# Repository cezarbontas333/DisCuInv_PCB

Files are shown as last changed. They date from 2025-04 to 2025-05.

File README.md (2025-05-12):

# DisCuInv_PCB
DisCuInv is an inverter project that aims to implement a simpler power conversion strategy. The aim is to be used in solar to grid conduction, but this is only a prototype used in an educational environment to test different plant control algorithms which may be less computational intensive and less complex to implement, like PIDs or RSTs. It contains a KiCAD project, namely schematic and PCB design, that can be used to create Gerber files, BOM and CPL that can be sent to a manufacturer to create the boards. Additionally, a [proof of concept](https://github.com/cezarbontas333/DisCuInv_PID) program is provided in a separate repository that uses a PID to control the power conversion.

## Highlights
- Features integrated [half-bridge and gate drivers](https://www.infineon.com/cms/en/product/power/motor-control-ics/brushed-dc-motor-control-ics/single-half-bridge-ics/ifx007t/) that can sustain up to 40V DC inputs, but the module designed should use 24V DC.
- Control is done using Infineon's [PSoC C3M5](https://www.infineon.com/cms/en/product/microcontroller/32-bit-psoc-arm-cortex-microcontroller/32-bit-psoc-control-arm-cortex-m33-mcu/psoc-control-c3m/), a modern microcontroller with plenty of features designed for power conversion applications. Pins that are not dedicated to the specific application have been broken out to standard 2.54mm headers for additional expansion modules in testing and prototyping of bonus features.
- Has an integrated power source for the whole logic section of the board. No other power supplies needed, just a IEC C8 socket to be directly plugged.
- Contains on-board LEDs and buttons for testing purposes.

## Disclaimers
This project does not assume any liability or warranty in any state of functioning, including specified or not specified otherwise. The license included covers only the KiCAD project files as described by the schematic and boards design. Other files included as additional resources and dependencies such as component footprints, schematic symbols, datasheets or similar material are subject to their respective owners' licenses and should be treated as such. If any issues appear in this regard, please contact via the platforms issues section or email to the maintainer.

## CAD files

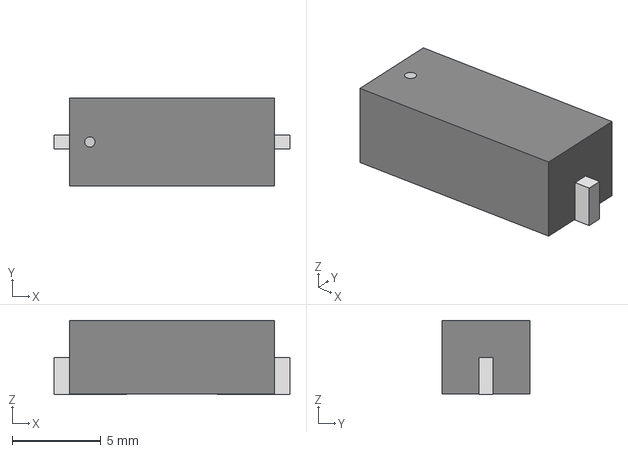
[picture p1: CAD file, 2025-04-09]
sol_inv/res/ABLS-16-000MHZ-B2-T/KiCADv6/XTAL_ABLS-16_ABR.step
13.3 x 4.98 x 4.19 mm

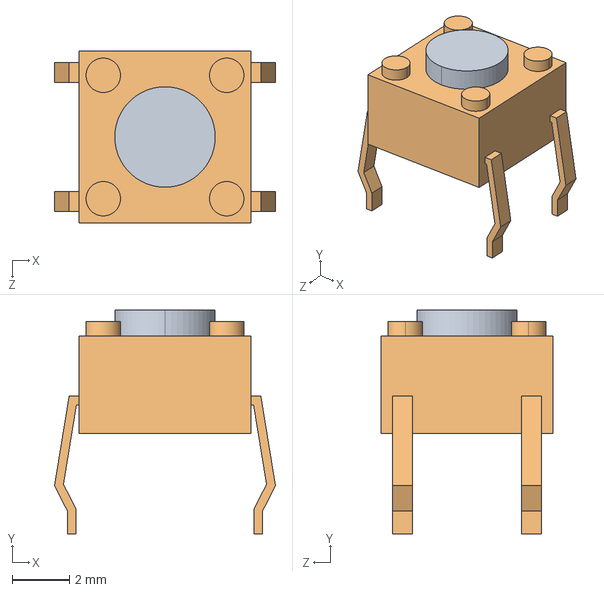
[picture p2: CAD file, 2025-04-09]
sol_inv/res/B3F-1000/KiCADv6/B3F_1000.step
7.70 x 7.80 x 6.00 mm
B3F_1002_BUTTON
B3F_1002_BASE

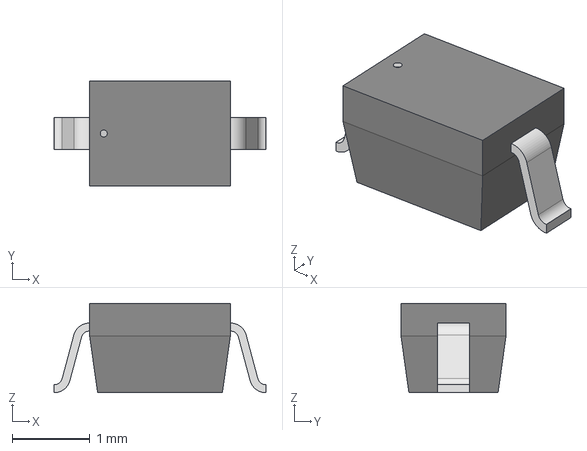
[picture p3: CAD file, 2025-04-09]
sol_inv/res/ESD12VD3B_TP/KiCADv6/CR_ESD_MCC.step
2.72 x 1.35 x 1.15 mm

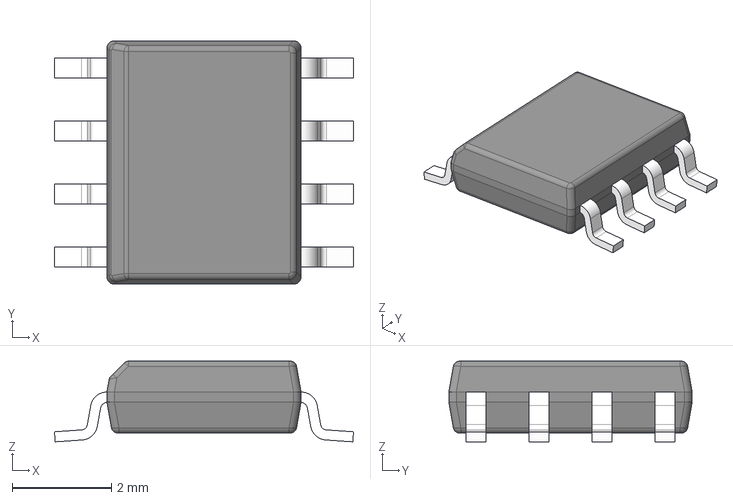
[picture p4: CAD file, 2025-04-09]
sol_inv/res/INA240A1D/KiCADv6/D0008A.stp
6.02 x 4.90 x 1.63 mm
BODY-SO
LEAD-D0008A x 8

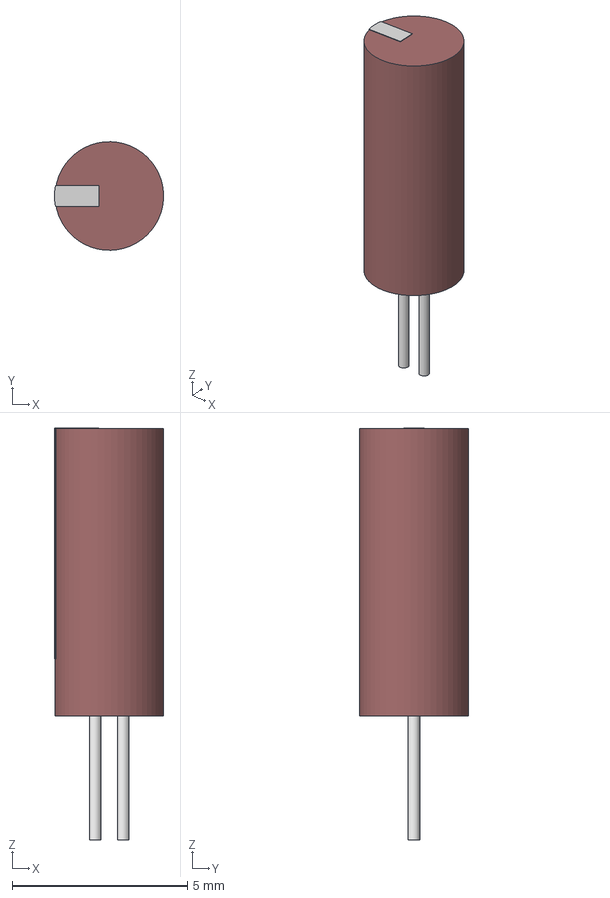
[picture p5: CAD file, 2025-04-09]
sol_inv/res/LFXTAL002995/KiCADv6/XTAL_LFXTAL002995BULK_IQD.step
3.11 x 3.10 x 11.8 mm

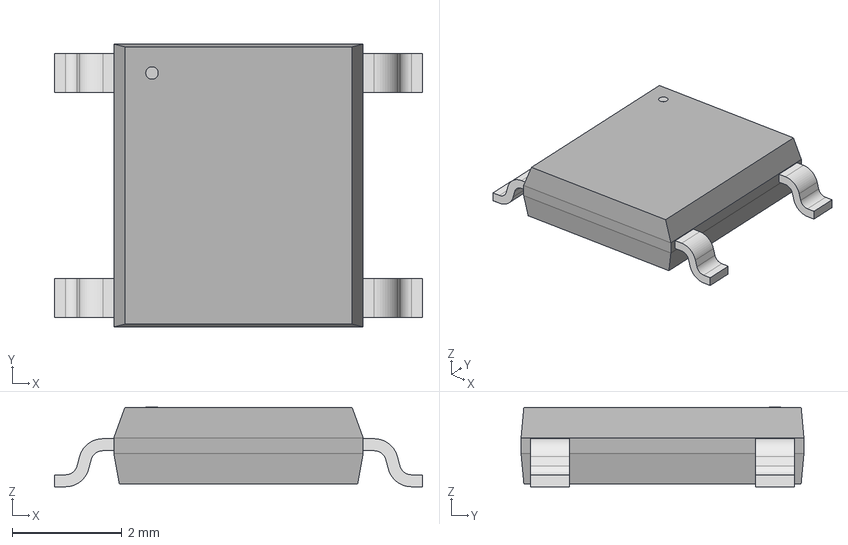
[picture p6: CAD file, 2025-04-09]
sol_inv/res/MDB6S/KiCADv6/BR_Micro-DIP4_OSI.step
6.71 x 5.16 x 1.45 mm

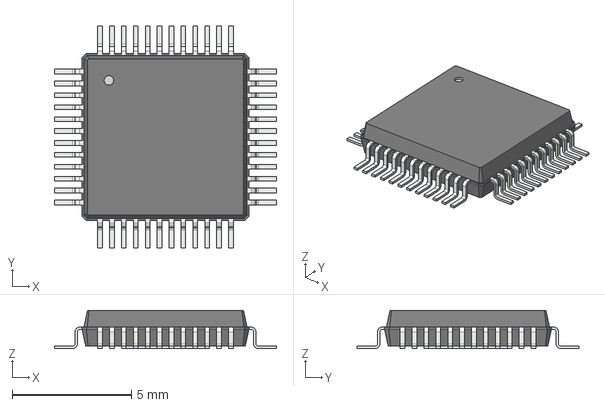
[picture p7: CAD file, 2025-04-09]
sol_inv/res/PSOC Control C3/Altium/E-LQFP-48/LQFP50P900X900X160-49N.step
9.32 x 9.32 x 1.60 mm

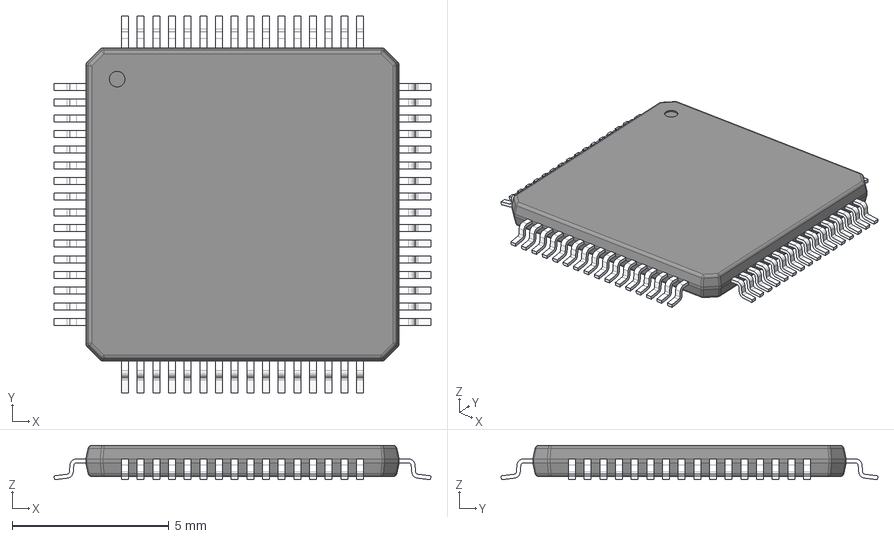
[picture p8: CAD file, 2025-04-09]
sol_inv/res/PSOC Control C3/Altium/E-LQFP-64/LQFP50P1200X1200X160-65N.stp
12.0 x 12.0 x 1.10 mm
BODY-QFP
LEAD-POWERPAD x 64
THERMALPAD-PWRPAD

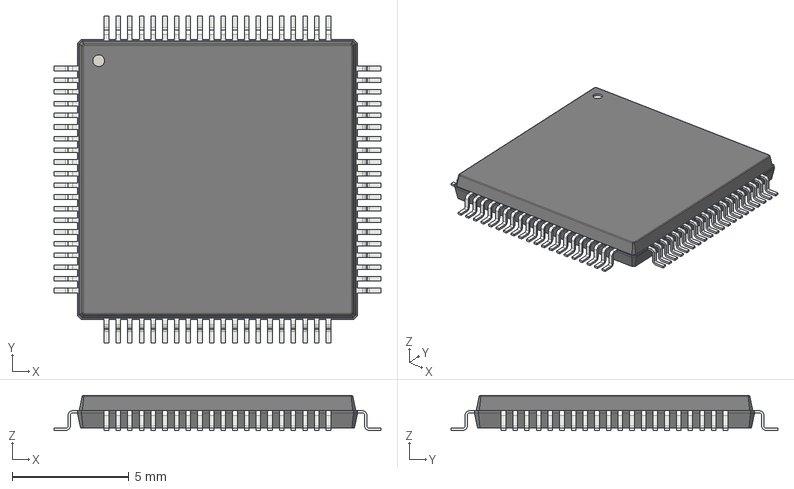
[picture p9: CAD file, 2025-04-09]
sol_inv/res/PSOC Control C3/Altium/E-LQFP-80/LQFP50P1400X1400X160-81N.step
14.0 x 14.0 x 1.50 mm

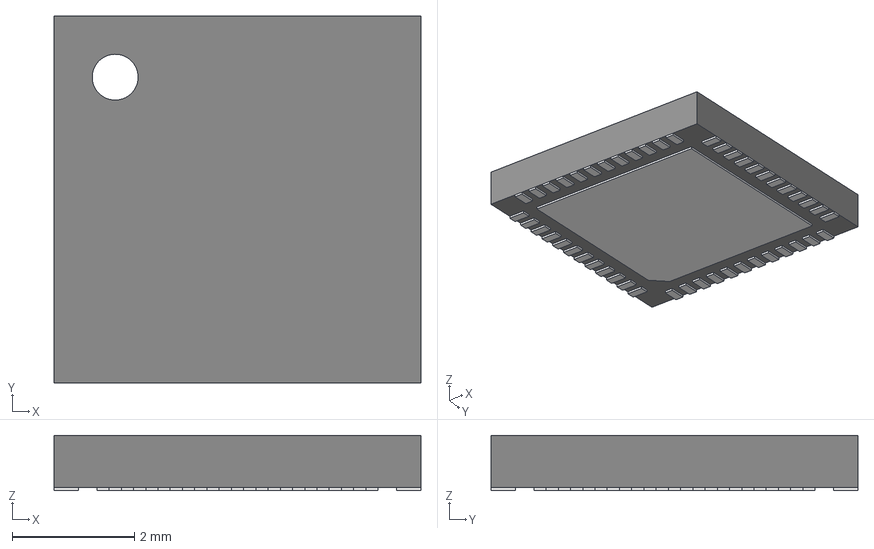
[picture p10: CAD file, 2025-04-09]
sol_inv/res/PSOC Control C3/Altium/VQFN-48/VQFN40P600X600X90-49N.step
6.00 x 6.00 x 0.9 mm
Open_CASCADE_STEP_translator_6.8_20.1
Open_CASCADE_STEP_translator_6.8_20.2.1
Thermal_Shape
Pin_Shape x 48

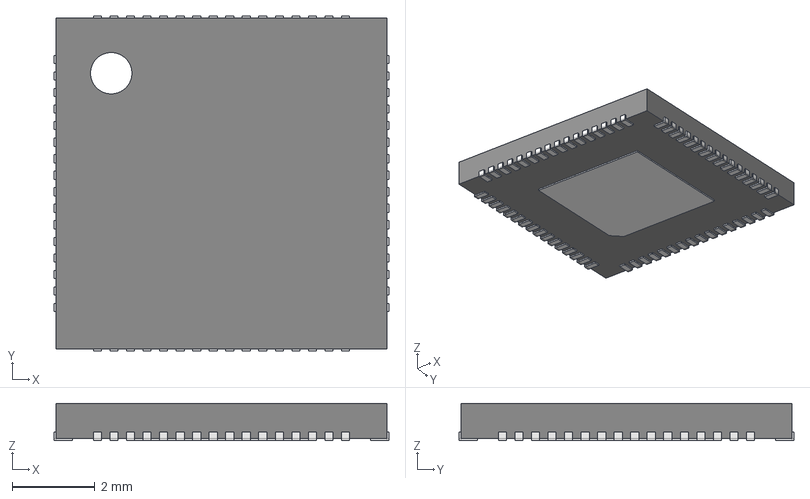
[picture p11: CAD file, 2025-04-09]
sol_inv/res/PSOC Control C3/Altium/VQFN-64/VQFN40P800X800X90-65N.step
8.10 x 8.10 x 0.9 mm
Open_CASCADE_STEP_translator_6.8_25.1
Open_CASCADE_STEP_translator_6.8_25.2.1
Thermal_Shape
Open_CASCADE_STEP_translator_6.8_25.4.1 x 64

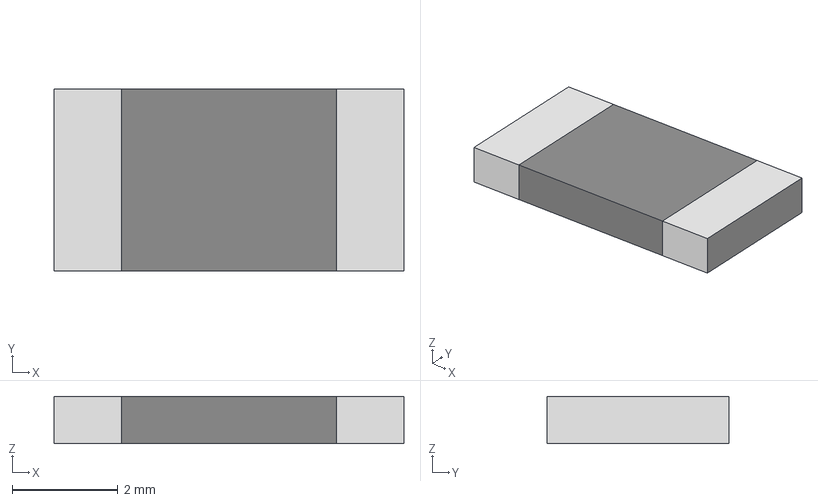
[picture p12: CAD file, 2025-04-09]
sol_inv/res/WSLP2512R0100FEA/KiCADv6/RES_VISHAY_WSLP2512_C_VIS.step
6.60 x 3.43 x 0.889 mm

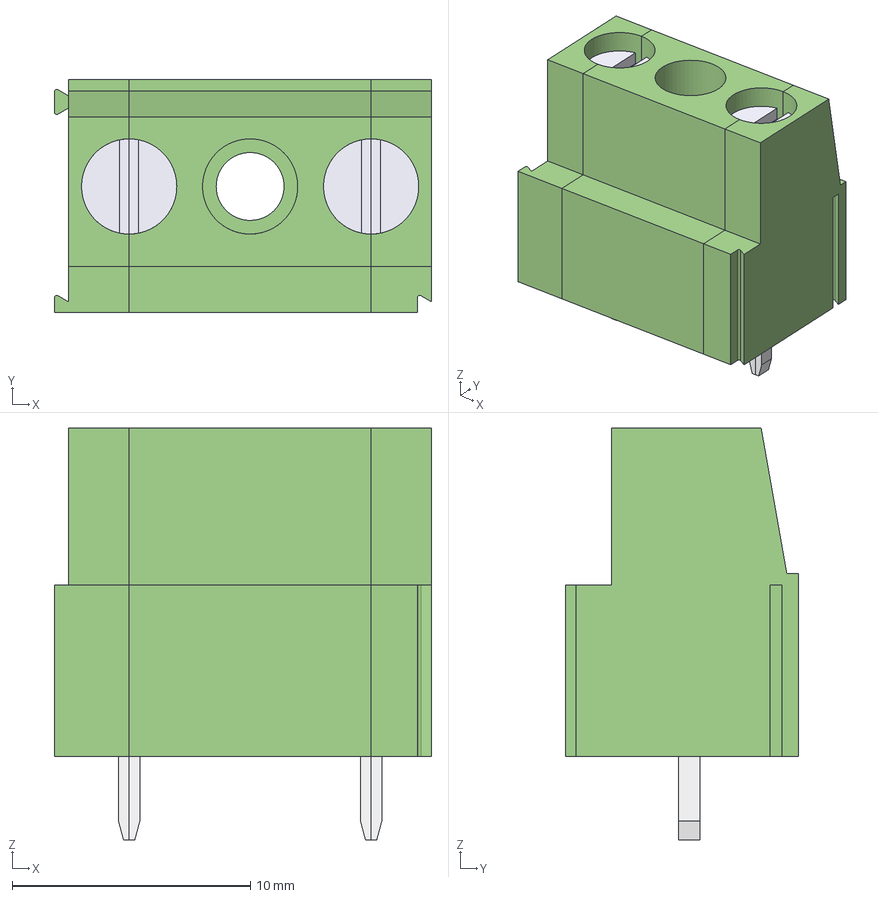
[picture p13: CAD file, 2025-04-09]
sol_inv/res/Wurth-691216610002/Download_STP_691216610002_rev1.stp
15.8 x 9.80 x 17.3 mm
CLL10.16_SX
CLL10.16_CNT
CLL10.16_DX

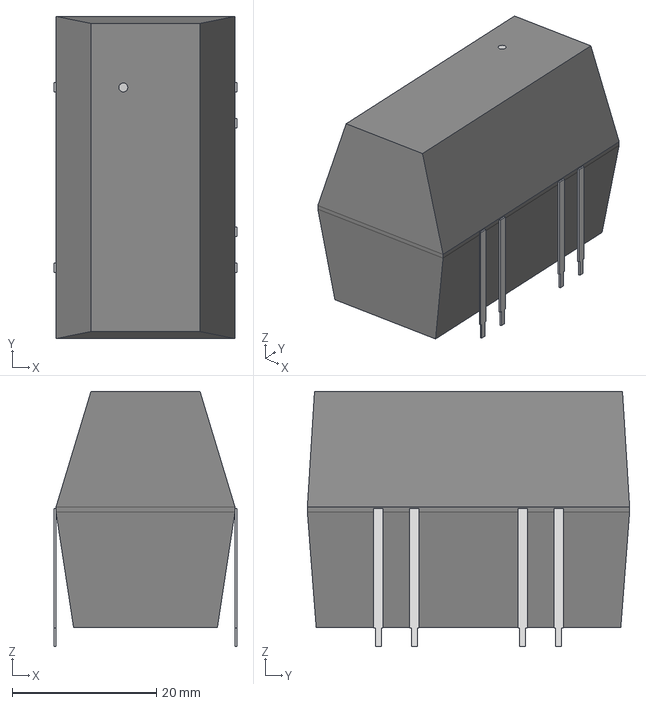
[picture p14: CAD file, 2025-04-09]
sol_inv/res/Myrra_44229/KiCADv6/44230_MYR.step
25.4 x 44.8 x 35.4 mm

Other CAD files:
sol_inv/res/WE-FLEX-749196521/749196521 (rev1).stp
sol_inv/res/WE-FLEX-749196521/749196521 (rev1).igs

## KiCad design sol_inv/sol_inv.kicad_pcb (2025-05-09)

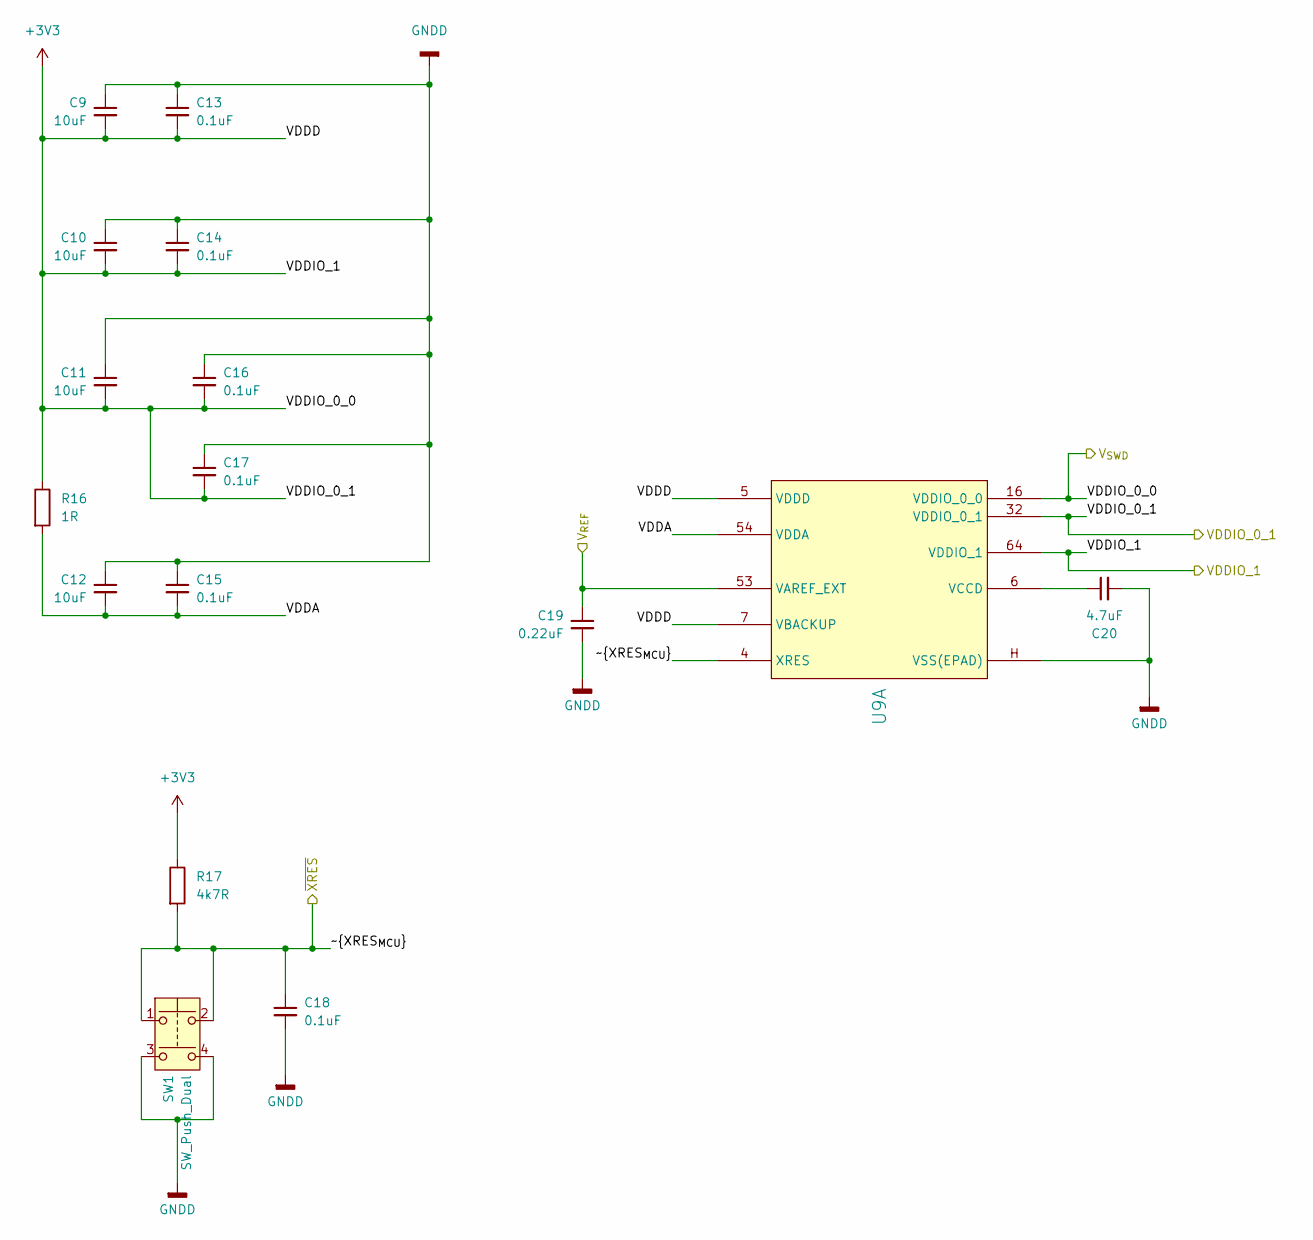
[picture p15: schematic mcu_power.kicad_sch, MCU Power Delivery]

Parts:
C9, C10, C11, C12: 10uF; C_0603_1608Metric
C13, C14, C15, C16, C17, C18: 0.1uF; C_0402_1005Metric
C19: 0.22uF; C_0402_1005Metric
C20: 4.7uF; C_0402_1005Metric
R16: 1R; R_0603_1608Metric
R17: 4k7R; R_0402_1005Metric
SW1: SW_Push_Dual; SW_B3F-1000_OMR
U9: PSC3M5_E-LQFP-64; LQFP50P1200X1200X160-65N

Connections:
+3V3: C9.2, C10.2, C11.2, C13.2, C14.2, C16.2, C17.2, R16.1, R17.1, U9.5 (VDDD), U9.7 (VBACKUP), U9.16 (VDDIO_0_0), U9.32 (VDDIO_0_1), U9.64 (VDDIO_1); also elsewhere on the board
/H-Bridge/V_{REF}: C19.1, U9.53 (VAREF_EXT); also elsewhere on the board
/MCU Power/VDDA: C12.2, C15.2, R16.2, U9.54 (VDDA)
/MCU Power/~XRES_{MCU}: C18.1, R17.2, SW1.1, SW1.2, U9.4 (XRES); also elsewhere on the board
GNDD: C9.1, C10.1, C11.1, C12.1, C13.1, C14.1, C15.1, C16.1, C17.1, C18.2, C19.2, C20.2, SW1.3, SW1.4, U9.H (VSS(EPAD)); also elsewhere on the board
unnamed: C20.1, U9.6 (VCCD)

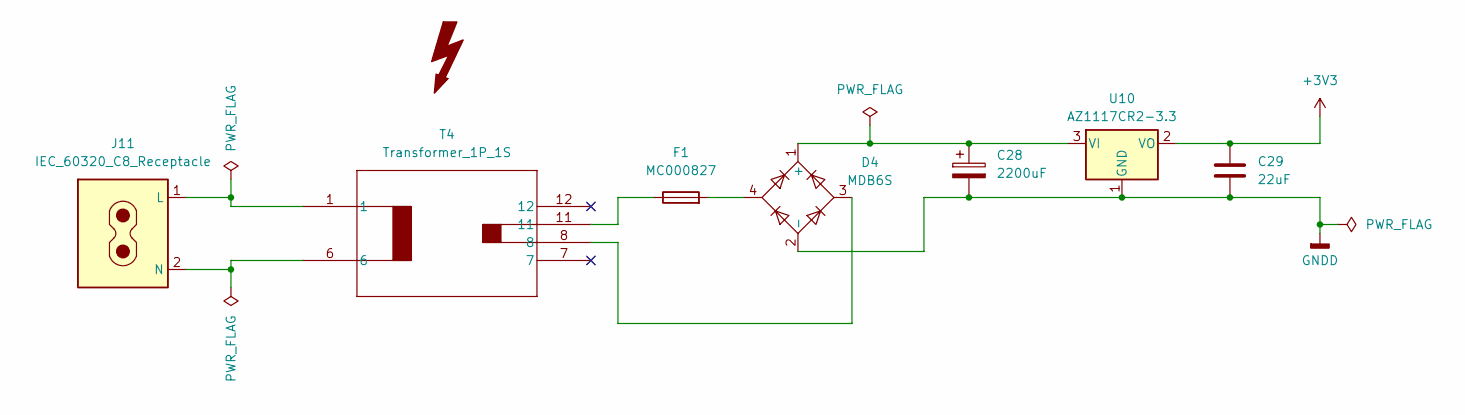
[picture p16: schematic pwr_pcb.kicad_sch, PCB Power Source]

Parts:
C28: 2200uF; CP_Radial_D10.0mm_P5.00mm
C29: 22uF; C_1206_3216Metric
D4: MDB6S; BR_Micro-DIP4_OSI
F1: MC000827; FUSE_MC000827_MTC
J11: IEC_60320_C8_Receptacle; 43000103
T4: Transformer_1P_1S; 44230_MYR
U10: AZ1117CR2-3.3; SOT-89-3

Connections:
+3V3: C29.1, U10.2 (VO); also elsewhere on the board
GNDD: C28.2, C29.2, D4.2 (-), U10.1 (GND); also elsewhere on the board
unnamed: C28.1, D4.1 (+), U10.3 (VI)
unnamed: D4.3, T4.8
unnamed: D4.4, F1.2
unnamed: F1.1, T4.11
unnamed: J11.1 (L), T4.1
unnamed: J11.2 (N), T4.6

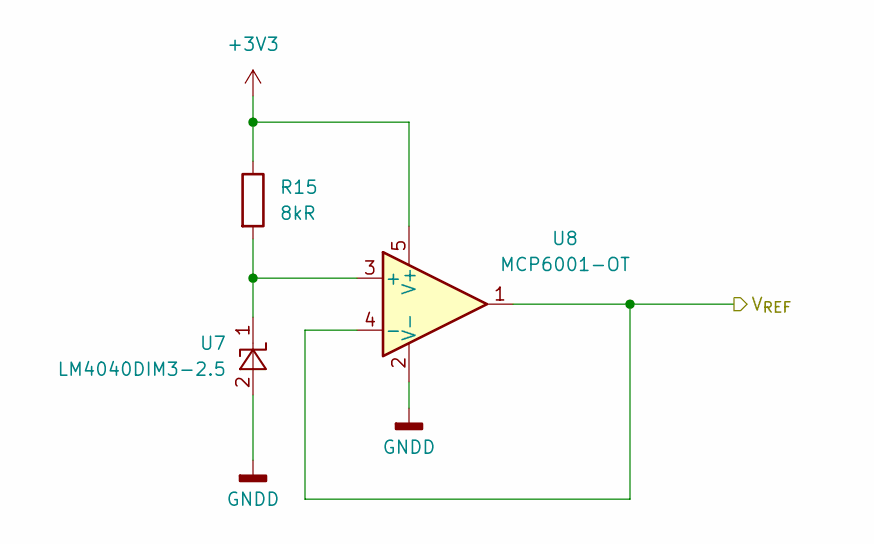
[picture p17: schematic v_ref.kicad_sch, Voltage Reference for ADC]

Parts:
R15: 8kR; R_0603_1608Metric
U7: LM4040DIM3-2.5; SOT-23-3
U8: MCP6001-OT; SOT-23-5

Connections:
+3V3: R15.1, U8.5 (V+); also elsewhere on the board
/H-Bridge/V_{REF}: U8.1, U8.4 (-); also elsewhere on the board
GNDD: U7.2 (A), U8.2 (V-); also elsewhere on the board
unnamed: R15.2, U7.1 (K), U8.3 (+)

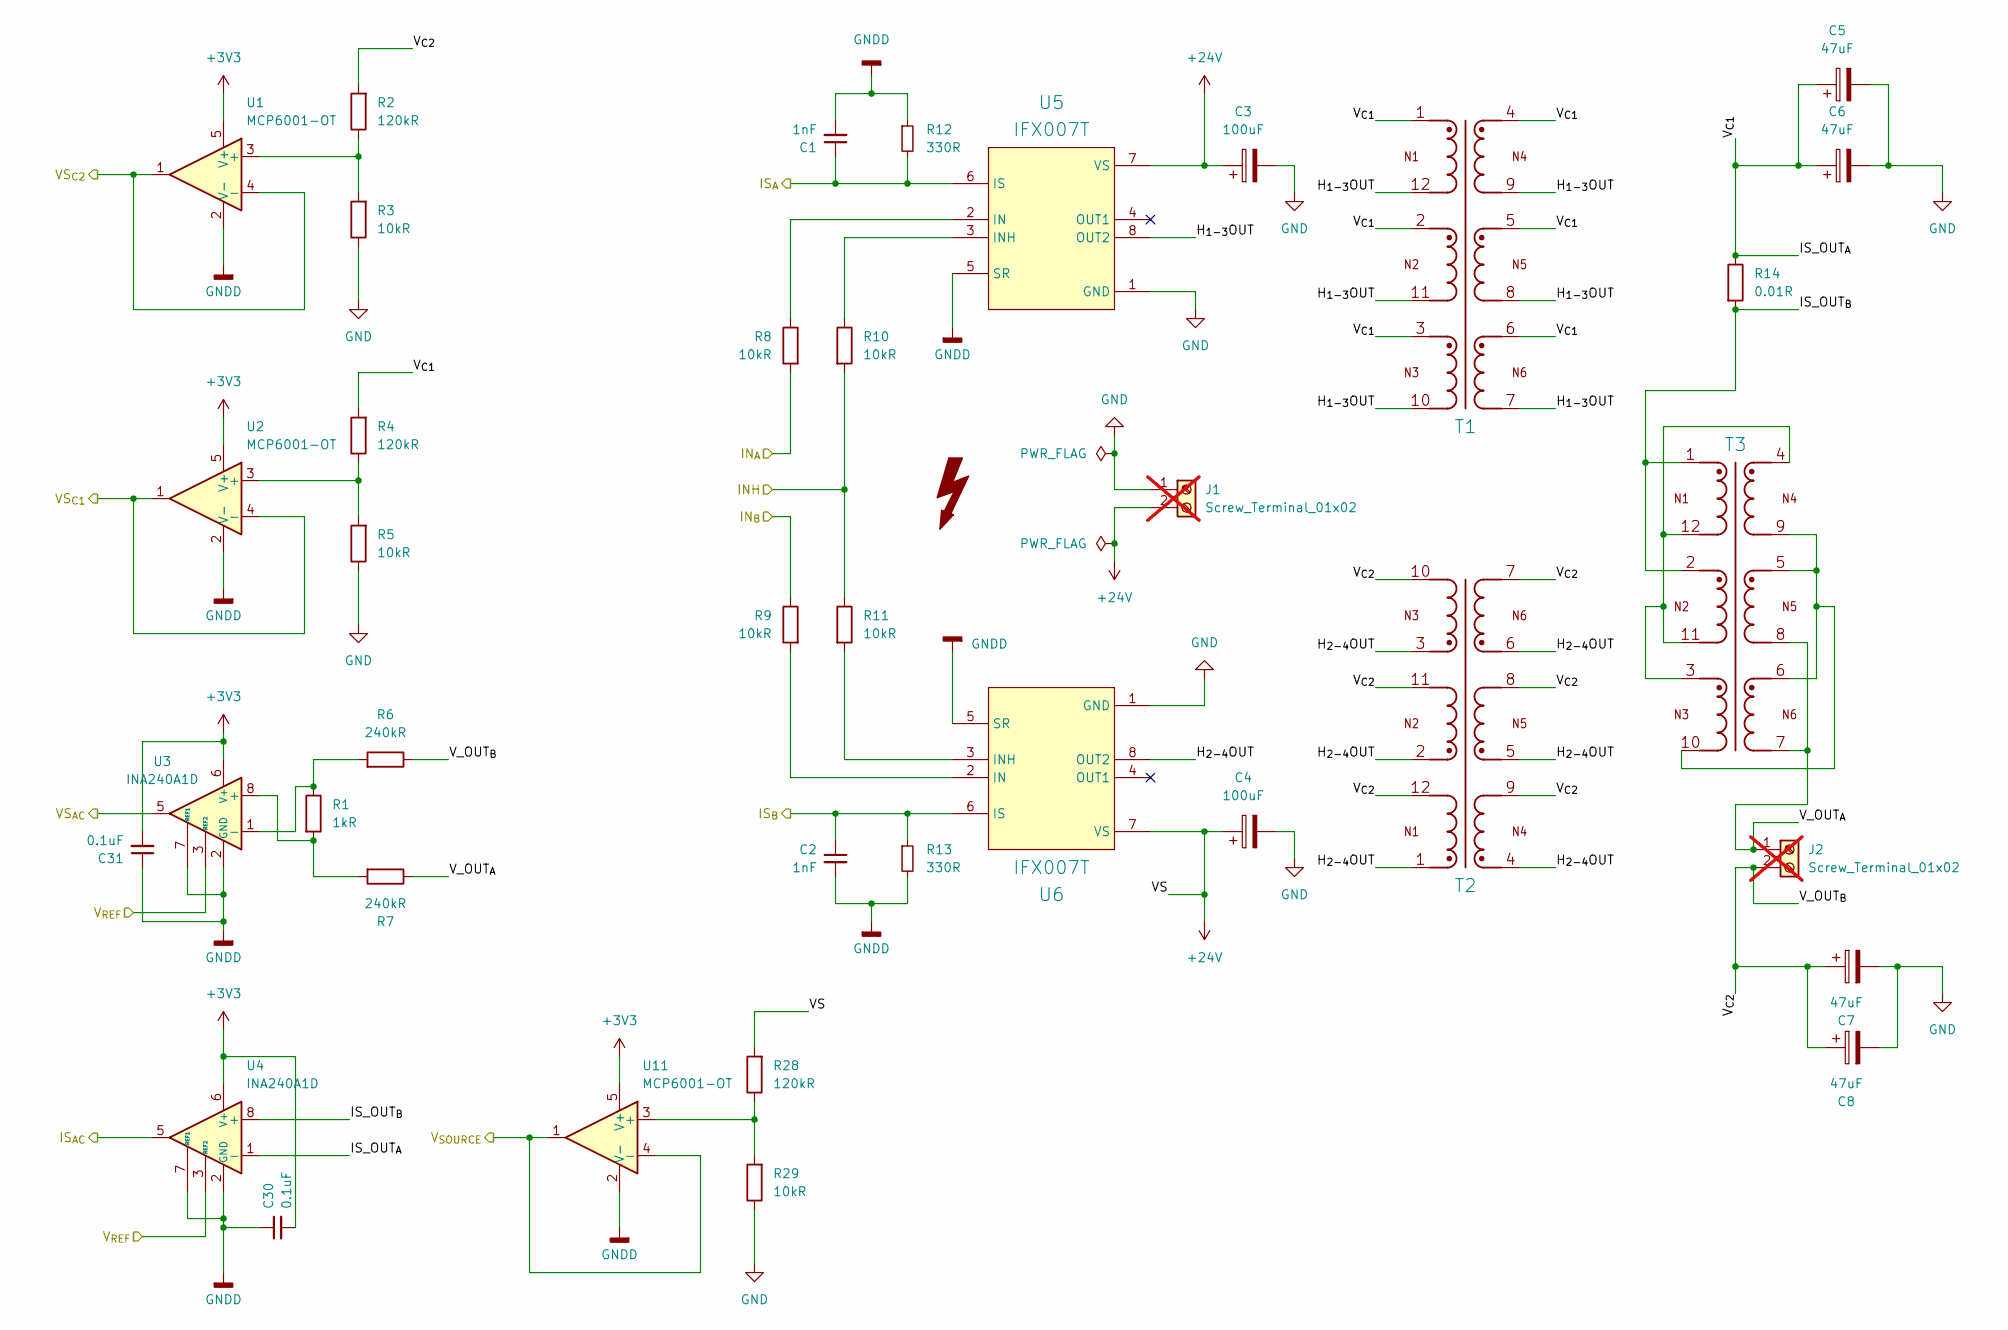
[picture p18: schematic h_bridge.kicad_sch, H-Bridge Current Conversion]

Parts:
C1, C2: 1nF; C_0603_1608Metric
C3, C4: 100uF; CP_Elec_8x10
C5, C6, C7, C8: 47uF; CP_Elec_8x10
C30, C31: 0.1uF; C_0402_1005Metric
J1, J2: Screw_Terminal_01x02; 691216610002_Handsolder; not fitted
R1: 1kR; R_0805_2012Metric
R2, R4, R28: 120kR; R_0805_2012Metric
R3, R5, R8, R9, R10, R11, R29: 10kR; R_0402_1005Metric
R6, R7: 240kR; R_0603_1608Metric
R12, R13: 330R; R_0603_1608Metric
R14: 0.01R; R_2512_6332Metric
T1, T2, T3: 12uH, 1.7A; WE-FLEX_EFD20; Voltage-µSecond Base 98.4uVs; Manufacturer Part Number 749196521
U1, U2, U11: MCP6001-OT; SOT-23-5
U3, U4: INA240A1D; D8_TEX
U5, U6: IFX007T; TO127P1500X440-8N-1-V

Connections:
+3V3: C30.2, C31.2, U1.5 (V+), U2.5 (V+), U3.6 (V+), U4.6 (V+), U11.5 (V+); also elsewhere on the board
+24V: C3.1, C4.1, J1.2, R28.2, U5.7 (VS), U6.7 (VS)
/H-Bridge/H_{1-3}OUT: T1.7, T1.8, T1.9, T1.10, T1.11, T1.12, U5.8 (OUT2)
/H-Bridge/H_{2-4}OUT: T2.1, T2.2, T2.3, T2.4, T2.5, T2.6, U6.8 (OUT2)
/H-Bridge/INH: R10.2, R11.1; also elsewhere on the board
/H-Bridge/IN_{A}: R8.2; also elsewhere on the board
/H-Bridge/IN_{B}: R9.1; also elsewhere on the board
/H-Bridge/IS_OUT_{A}: C5.1, C6.1, R4.2, R14.1, T1.1, T1.2, T1.3, T1.4, T1.5, T1.6, U4.1 (-)
/H-Bridge/IS_OUT_{B}: R14.2, T3.1, T3.2, U4.8 (+)
/H-Bridge/IS_{AC}: U4.5; also elsewhere on the board
/H-Bridge/IS_{A}: C1.1, R12.2, U5.6 (IS); also elsewhere on the board
/H-Bridge/IS_{B}: C2.1, R13.1, U6.6 (IS); also elsewhere on the board
/H-Bridge/VS_{AC}: U3.5; also elsewhere on the board
/H-Bridge/VS_{C1}: U2.1, U2.4 (-); also elsewhere on the board
/H-Bridge/VS_{C2}: U1.1, U1.4 (-); also elsewhere on the board
/H-Bridge/V_OUT_{A}: J2.1, R7.1, T3.7, T3.8
/H-Bridge/V_OUT_{B}: C7.1, C8.1, J2.2, R2.2, R6.1, T2.7, T2.8, T2.9, T2.10, T2.11, T2.12
/H-Bridge/V_{REF}: U3.3 (REF2), U4.3 (REF2); also elsewhere on the board
/H-Bridge/V_{SOURCE}: U11.1, U11.4 (-); also elsewhere on the board
GND: C3.2, C4.2, C5.2, C6.2, C7.2, C8.2, J1.1, R3.1, R5.1, R29.1, U5.1 (GND), U6.1 (GND)
GNDD: C1.2, C2.2, C30.1, C31.1, R12.1, R13.2, U1.2 (V-), U2.2 (V-), U3.2 (GND), U3.4 (GND), U3.7 (REF1), U4.2 (GND), U4.4 (GND), U4.7 (REF1), U5.5 (SR), U6.5 (SR), U11.2 (V-); also elsewhere on the board
unnamed: T3.5, T3.6, T3.9, T3.10
unnamed: T3.3, T3.4, T3.11, T3.12
unnamed: R2.1, R3.2, U1.3 (+)
unnamed: R4.1, R5.2, U2.3 (+)
unnamed: R1.2, R7.2, U3.8 (+)
unnamed: R1.1, R6.2, U3.1 (-)
unnamed: R8.1, U5.2 (IN)
unnamed: R10.1, U5.3 (INH)
unnamed: R9.2, U6.2 (IN)
unnamed: R11.2, U6.3 (INH)
unnamed: R28.1, R29.2, U11.3 (+)

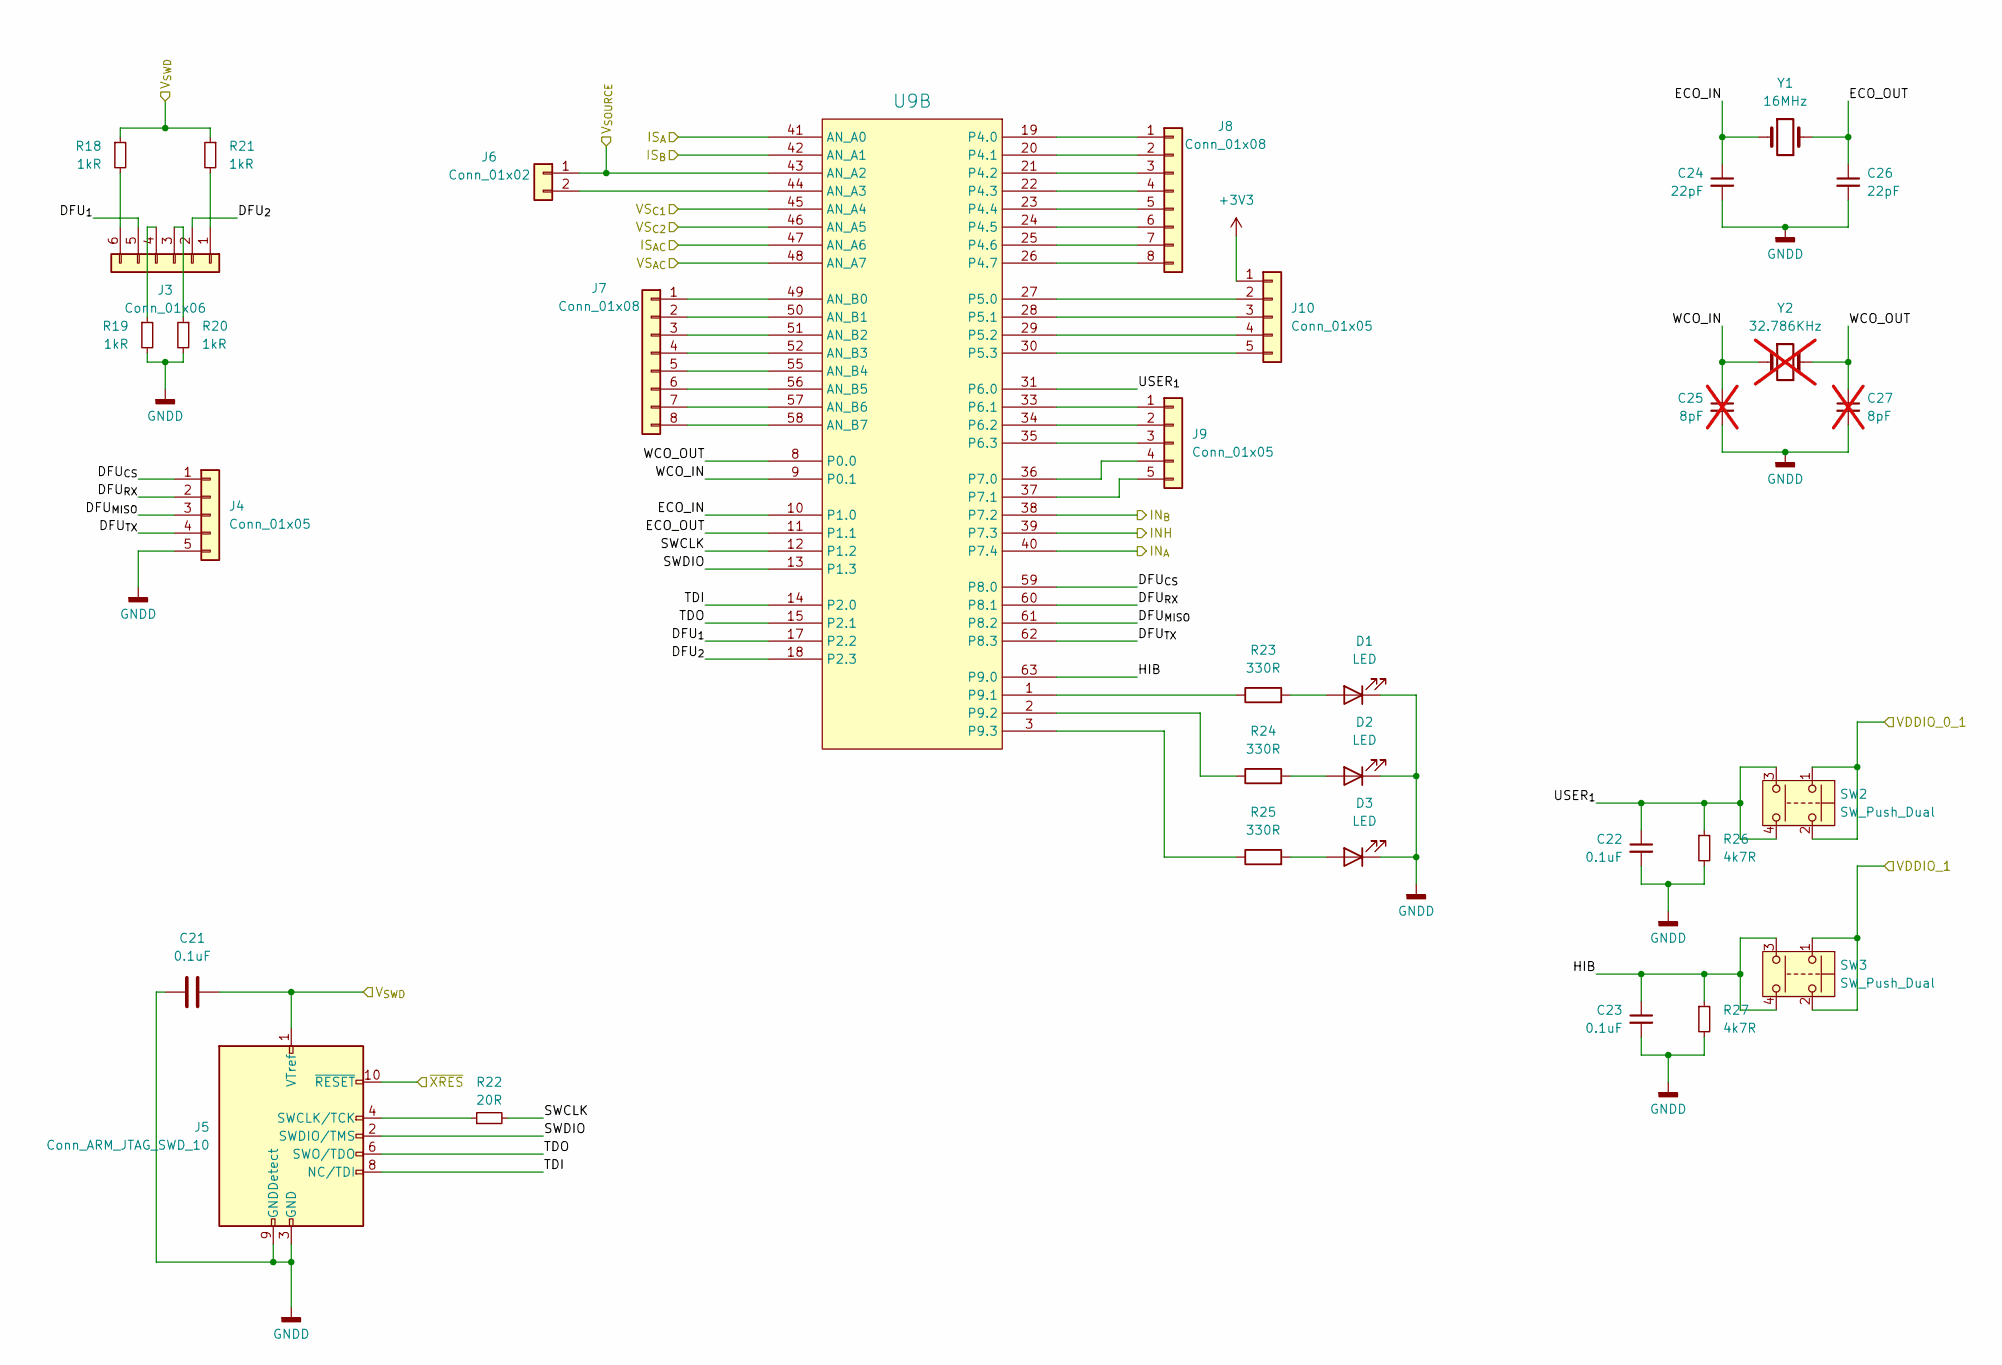
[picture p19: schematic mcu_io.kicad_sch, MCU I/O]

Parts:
C21, C22, C23: 0.1uF; C_0402_1005Metric
C24, C26: 22pF; C_0805_2012Metric
C25, C27: 8pF; C_0402_1005Metric; not fitted
D1, D2, D3: LED; LED_0603_1608Metric
J3: Conn_01x06; PinHeader_1x06_P2.54mm_Vertical
J4, J9, J10: Conn_01x05; PinSocket_1x05_P2.54mm_Vertical
J5: Conn_ARM_JTAG_SWD_10; PinHeader_2x05_P1.27mm_Vertical
J6: Conn_01x02; PinSocket_1x02_P2.54mm_Vertical
J7, J8: Conn_01x08; PinSocket_1x08_P2.54mm_Vertical
R18, R19, R20, R21: 1kR; R_0805_2012Metric
R22: 20R; R_1206_3216Metric
R23, R24, R25: 330R; R_0603_1608Metric
R26, R27: 4k7R; R_0402_1005Metric
SW2, SW3: SW_Push_Dual; SW_B3F-1000_OMR
U9: PSC3M5_E-LQFP-64; LQFP50P1200X1200X160-65N
Y1: 16MHz; ABLS7
Y2: 32.786KHz; XTAL_LFXTAL002995BULK_IQD; not fitted

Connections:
+3V3: C21.1, J5.1 (VTref), J10.1, R18.1, R21.1, SW2.1, SW2.2, SW3.1, SW3.2; also elsewhere on the board
/H-Bridge/INH: U9.39 (P7.3); also elsewhere on the board
/H-Bridge/IN_{A}: U9.40 (P7.4); also elsewhere on the board
/H-Bridge/IN_{B}: U9.38 (P7.2); also elsewhere on the board
/H-Bridge/IS_{AC}: U9.47 (AN_A6); also elsewhere on the board
/H-Bridge/IS_{A}: U9.41 (AN_A0); also elsewhere on the board
/H-Bridge/IS_{B}: U9.42 (AN_A1); also elsewhere on the board
/H-Bridge/VS_{AC}: U9.48 (AN_A7); also elsewhere on the board
/H-Bridge/VS_{C1}: U9.45 (AN_A4); also elsewhere on the board
/H-Bridge/VS_{C2}: U9.46 (AN_A5); also elsewhere on the board
/H-Bridge/V_{SOURCE}: J6.1, U9.43 (AN_A2); also elsewhere on the board
/MCU IO/DFU_{1}: J3.5, U9.17 (P2.2)
/MCU IO/DFU_{2}: J3.2, U9.18 (P2.3)
/MCU IO/DFU_{CS}: J4.1, U9.59 (P8.0)
/MCU IO/DFU_{MISO}: J4.3, U9.61 (P8.2)
/MCU IO/DFU_{RX}: J4.2, U9.60 (P8.1)
/MCU IO/DFU_{TX}: J4.4, U9.62 (P8.3)
/MCU IO/ECO_IN: C24.1, U9.10 (P1.0), Y1.1
/MCU IO/ECO_OUT: C26.1, U9.11 (P1.1), Y1.2
/MCU IO/HIB: C23.1, R27.1, SW3.3, SW3.4, U9.63 (P9.0)
/MCU IO/SWCLK: R22.2, U9.12 (P1.2)
/MCU IO/SWDIO: J5.2 (SWDIO/TMS), U9.13 (P1.3)
/MCU IO/TDI: J5.8 (NC/TDI), U9.14 (P2.0)
/MCU IO/TDO: J5.6 (SWO/TDO), U9.15 (P2.1)
/MCU IO/USER_{1}: C22.1, R26.1, SW2.3, SW2.4, U9.31 (P6.0)
/MCU IO/WCO_IN: C25.1, U9.9 (P0.1), Y2.1
/MCU IO/WCO_OUT: C27.1, U9.8 (P0.0), Y2.2
/MCU Power/~XRES_{MCU}: J5.10 (~RESET); also elsewhere on the board
GNDD: C21.2, C22.2, C23.2, C24.2, C25.2, C26.2, C27.2, D1.1 (K), D2.1 (K), D3.1 (K), J4.5, J5.3 (GND), J5.5 (GND), J5.9 (GNDDetect), R19.2, R20.2, R26.2, R27.2; also elsewhere on the board
unnamed: D1.2 (A), R23.2
unnamed: D2.2 (A), R24.2
unnamed: D3.2 (A), R25.2
unnamed: J3.1, R21.2
unnamed: J3.3, R20.1
unnamed: J3.4, R19.1
unnamed: J3.6, R18.2
unnamed: J5.4 (SWCLK/TCK), R22.1
unnamed: J6.2, U9.44 (AN_A3)
unnamed: J7.1, U9.49 (AN_B0)
unnamed: J7.2, U9.50 (AN_B1)
unnamed: J7.3, U9.51 (AN_B2)
unnamed: J7.4, U9.52 (AN_B3)
unnamed: J7.5, U9.55 (AN_B4)
unnamed: J7.6, U9.56 (AN_B5)
unnamed: J7.7, U9.57 (AN_B6)
unnamed: J7.8, U9.58 (AN_B7)
unnamed: J8.1, U9.19 (P4.0)
unnamed: J8.2, U9.20 (P4.1)
unnamed: J8.3, U9.21 (P4.2)
unnamed: J8.4, U9.22 (P4.3)
unnamed: J8.5, U9.23 (P4.4)
unnamed: J8.6, U9.24 (P4.5)
unnamed: J8.7, U9.25 (P4.6)
unnamed: J8.8, U9.26 (P4.7)
unnamed: J9.1, U9.33 (P6.1)
unnamed: J9.2, U9.34 (P6.2)
unnamed: J9.3, U9.35 (P6.3)
unnamed: J9.4, U9.36 (P7.0)
unnamed: J9.5, U9.37 (P7.1)
unnamed: J10.2, U9.27 (P5.0)
unnamed: J10.3, U9.28 (P5.1)
unnamed: J10.4, U9.29 (P5.2)
unnamed: J10.5, U9.30 (P5.3)
unnamed: R23.1, U9.1 (P9.1)
unnamed: R24.1, U9.2 (P9.2)
unnamed: R25.1, U9.3 (P9.3)

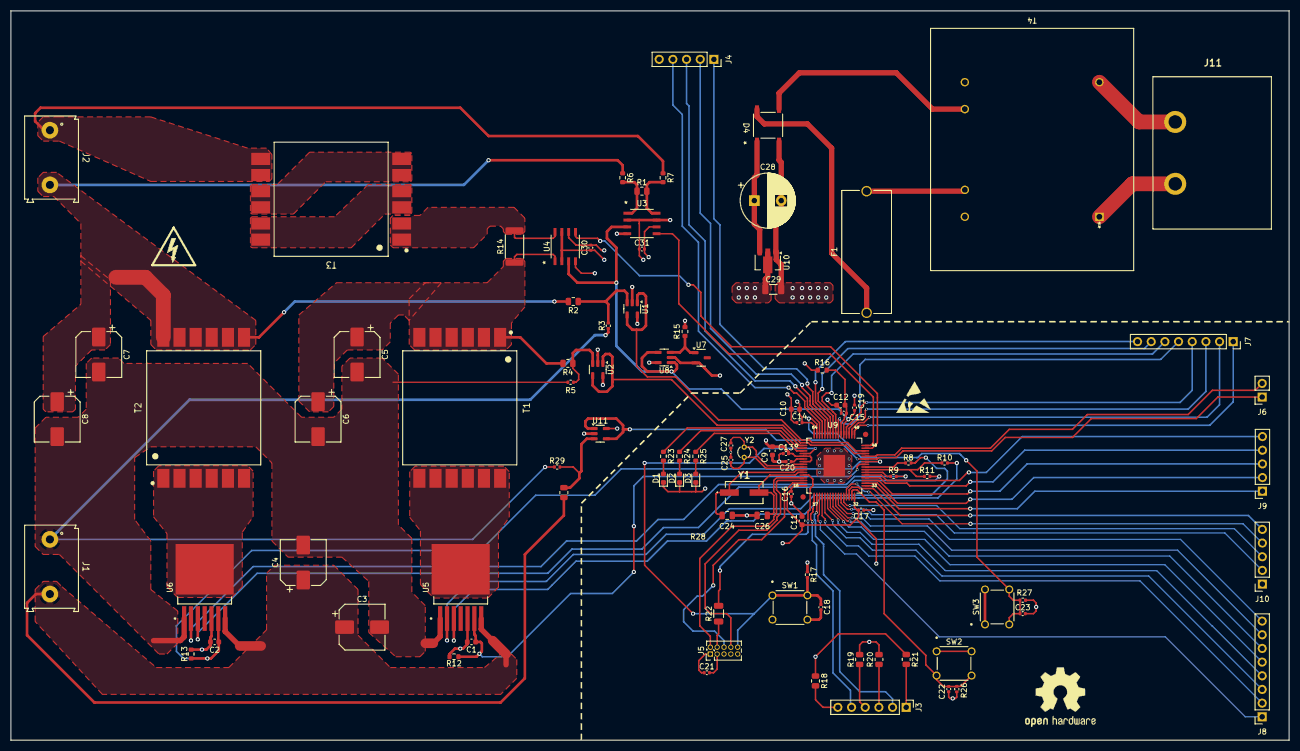
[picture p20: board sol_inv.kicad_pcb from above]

Board: 4 copper layers, 237.5 x 135.5 mm, 96 parts (0 on the bottom side), 95 nets.

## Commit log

2025-04-09 0.1v full schematic done
    [44230_MYR.step, 749196521 (rev1).igs, 749196521 (rev1).stp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]
2025-04-22 v0.2 components change + reference to providers
    [h_bridge.kicad_sch, mcu_io.kicad_sch, mcu_power.kicad_sch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]
2025-04-24 initial component placement
    [44230_MYR.step, 749196521 (rev1).igs, 749196521 (rev1).stp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]
2025-05-05 v0.3 pcb layout pre-drc fixes
    [h_bridge.kicad_sch, mcu_io.kicad_sch, mcu_power.kicad_sch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]
2025-05-08 v0.3.1 drc fixes + layout tweaks
    [h_bridge.kicad_sch, sol_inv.kicad_pcb]
2025-05-09 v0.3.2 hbridge plane tweaks
    [sol_inv.kicad_pcb]

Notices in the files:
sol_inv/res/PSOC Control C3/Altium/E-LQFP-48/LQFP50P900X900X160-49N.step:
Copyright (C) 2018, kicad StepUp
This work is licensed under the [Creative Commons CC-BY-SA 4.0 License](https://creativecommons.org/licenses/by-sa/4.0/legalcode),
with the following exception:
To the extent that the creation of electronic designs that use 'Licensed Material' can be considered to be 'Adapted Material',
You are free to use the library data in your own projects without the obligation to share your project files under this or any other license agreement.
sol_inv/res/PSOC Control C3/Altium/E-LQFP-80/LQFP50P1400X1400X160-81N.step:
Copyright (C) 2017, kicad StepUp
